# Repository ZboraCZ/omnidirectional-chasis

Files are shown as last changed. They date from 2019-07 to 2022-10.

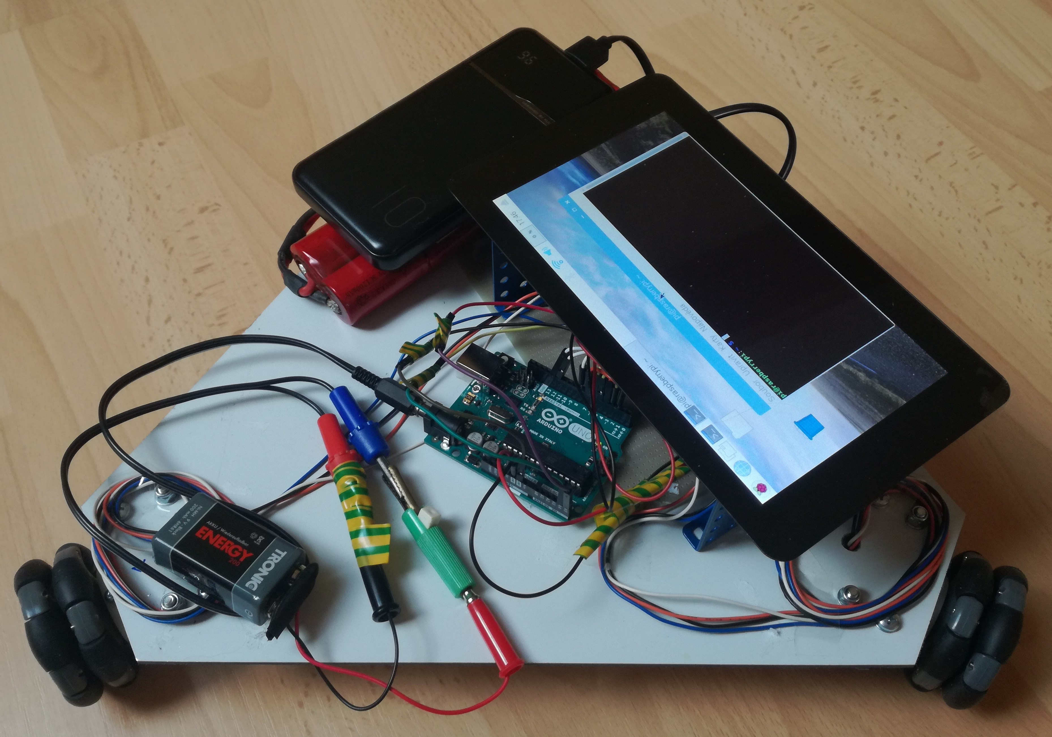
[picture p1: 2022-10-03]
Final_chasis_photo.jpg

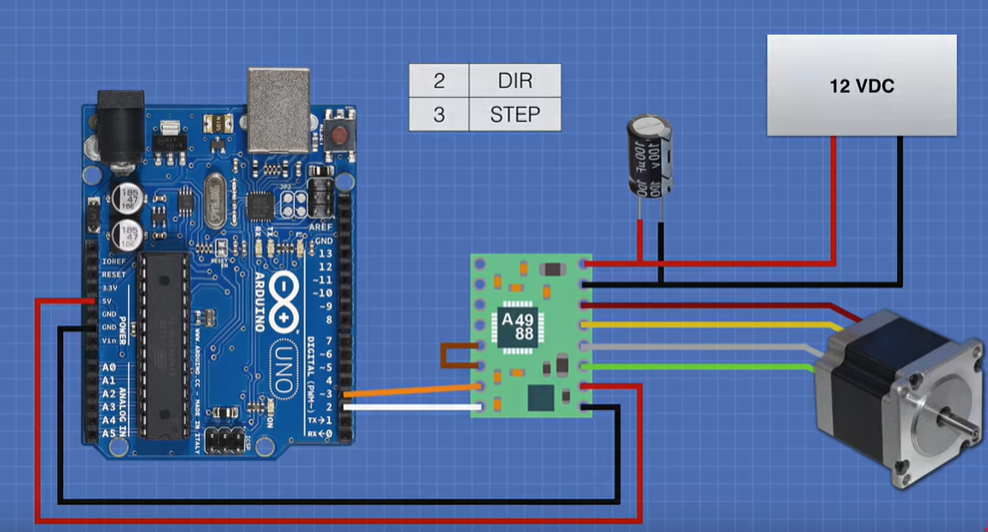
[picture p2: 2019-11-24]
Dokumentace/Obrázky/Zapojení_jednoho_motoru-UKÁZKA_YT.PNG

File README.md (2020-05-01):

# TODO list
* Max speed is 450. Needs to be replaced in codes from 200
* AND ITS TO 15 NOT 16 ON 4 BITS FFS WHAT AN IDIOT I AM
* AND THE CONSTANT FOR MODIFYING THE SPEED IS 30 YOU IDIOT
* disableOutputs enables to Arduino using motors. Its like negative
* Take photo of RPi and Arduino for Thesis.
* Build again just i2c comm Arduino-RPi
	* Make all new scripts bash executables: chmod a+x /path/to/file or chmod 777 /path/to/file
	* TOTEST: Response scripts from Arduino back to Raspberry Pi (new waiting method in RPi scripts)
	* Test all Instruction primitives
	* Try running the SQUARE combined instruction
* Try to build complete chasis with all motors on non-soldering array, try to USE ALL 3 100uF transistors from Arduino set
* Take photo of complete chasis build for Thesis.
* Take video of the chasis move.
	* Make a square move anticlockwise, rotate 360 left, then 360 right. Go the square back clockwise.
* Try build the chasis with all motors on soldering array, try to USE ALL 3 100uF transistors from Arduino set if worked
* LETS ROLL!

# Bachelor thesis: Design and control of omnidirectional chasis.

## Running Raspberry Pi Shell scripts manual
### go.sh [int degrees] [int speedLevel]
int degrees: ° from 0 to 360 defining the way chasis will go. 0° is right, 90° is front.
int speedLevel: Number from 1 to 16 defining how quickly will the motors rotate up to 200 steps per second.

### rotate.sh [int degrees] [int direction]
int degrees: ° from 0 to 360 defining how much will the chasis rotate.
int direction: Number 0 or 1. 0 is rotation left(anticlockwise), 1 is rotation right(clockwise)

### brake.sh
Doesn't take arguments. Holds the motors still.

### stop.sh
Doesn't take arguments. Disables powering of the motors.

### setSpeed.sh [int speedLevel]
int speedLevel: Number from 1 to 16 defining how quickly will the motors rotate up to 200 steps per second.
Just sets speed of motors. Doesn't move anything.

## Checking I2C connection addresses table on Raspberry Pi:
sudo i2cdetect -y 1

# Maybe for future controlling with PS4 Dualshock Controller device
Scripts in the folder "ZZZ_unused_Controlling_motors_PS4_controller"
Workflow to start control of the Raspberry Pi:
1. sudo ds4drv, then start controller //Dualshock 4 controller will connect
2. start Main.py to start controlling

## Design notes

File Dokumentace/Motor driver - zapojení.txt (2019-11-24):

Zapojení krokového motoru správným směrem pro kladná čísla - Otáčení na podvozku proti směru hodinových ručiček:
B2 oražová
A2 černá
A1 modrá
B1 bílá

MS1, MS2,MS3: Připojují se na 5V, pokud chceme měnit full step, 1/8 step nebo 1/16 step podle tabulky

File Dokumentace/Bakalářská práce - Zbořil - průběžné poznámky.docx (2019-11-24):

# Bakalářská práce – průběžné poznámky

# Původní návrh Matematiky počítání rychlostí motorů na Raspberry Pi v krocích

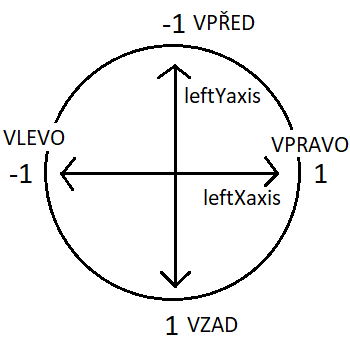
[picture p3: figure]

Plán ovládání podvozku byl takový, že bude ovládán analogovým ovladačem určeným pro herní konzole a jiné platformy. Od tohoto návrhu se ustoupilo hlavně z toho důvodu, že závislost na specifickém ovládacím zařízení je nežádoucí a nepraktická.

Kroky jsou určeny především pro levou páčku určující pohyb podvozku.

Předpoklad je ten, že uživatel pohnul jednou, nebo druhou páčkou. V opačném případě se nic neděje.

Hodnoty do daných směrů páček ovladače jsou popsány na obrázku.

# 1.krok

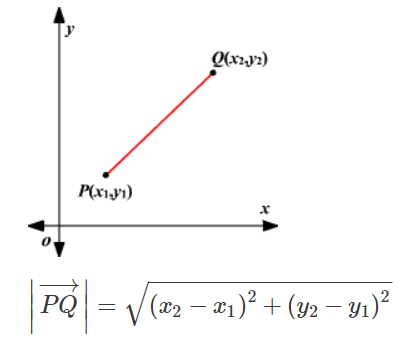
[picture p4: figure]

## Výpočet velikosti vektoru (jak daleko je páčka od jejího středu)

magnitude = math.sqrt( math.pow(leftXaxis, 2) + math.pow(leftYaxis, 2) )

# 1,5.krok-Důležitý mezikrok

## Ujištění se nepřekročení maximální hodnoty velikosti vektoru magnitude

Pokud se povede vypočítat velikost vektoru (dále jen magnitude) větší než 1, přiřadíme mu 1… Nesmíme překračovat hranice maximálních hodnot – otáčky motorů by mohly překročit hranici.

if magnitude > 1: magnitude = 1

# 2.krok

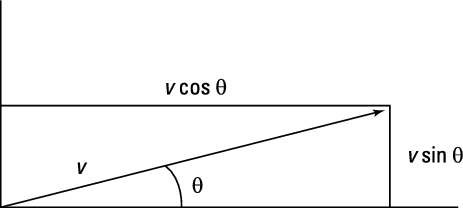
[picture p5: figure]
VÃ½sledek obrÃ¡zku pro direction of vector

## Určení směru vektoru páčky (direction of vector)

Směr vektoru je velikost úhlu od vodorovné osy X – nad osou je úhel kladný, pod osou záporný. Vzorec je dělení dvěma čísly, přičemž ani u jednoho se nepřipouští nulová hodnota, protože by rozbila celý výpočet. Minimální hodnotu blízko nule kterémukoliv číslu musíme oželit, i když to bude velice malá nepřesnost.
(Výsledek směru vektoru se v matematice označuje písmenkem THETA.)

if leftXaxis == 0: leftXaxis = 0.0000001
if leftYaxis == 0: leftYaxis = 0.0000001

direction = math.atan( leftYaxis/leftXaxis )

# 2,5.krok – Důležitý mezikrok

## Přepočet směru vektoru od 0° a nebo 180°(PI)

Zde přepočet vždy vychází správně pouze do 90° a v mé matematice vždy vycházela čísla pouze v úhlech vpravo od svislé osy Y. Musím zjistit, zda se posouvám vlevo nebo vpravo, a podle toho určit směr vektoru od 0° nebo 180°.

if leftXaxis < 0: direction = math.pi – direction

elif leftXaxis > 0: direction = 0 – direction

# 3.krok

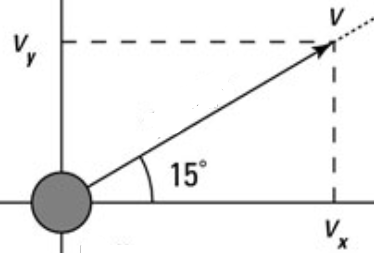
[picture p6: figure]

## Určení vektorových komponent Vx a Vy.

Využívá se zde směru páčky, který jsme vypočítali. Tyto vektorové komponenty poté ve finálním kroku slouží jako konstanty pro jasné určení jak rychlosti otáček jednotlivých motorů tak orientace jejich otáčení (vpřed nebo vzad).

vectorX = math.cos(direction) * magnitude
vectorY = math.sin(direction) * magnitude

# 4.krok

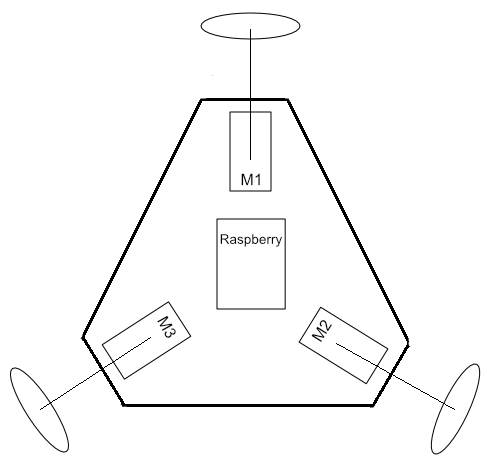
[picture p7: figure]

## Určení rychlostí jednotlivých motorů

Motor1 se pohybuje pouze na ose X, tedy počítání s komponentou Vy nemá význam.
Motor2 i Motor3 se pohybují v obou osách, vzorec je tedy o něco složitější.

motor1Speed = -1 * (vectorX)
motor2Speed = 0.5*vectorX + math.sqrt(3/2)*vectorY
motor3Speed = 0.5*vectorX - math.sqrt(3/2)*vectorY

# 5.krok

## Ujištění se maximálních hodnot pro motory a jejich vynásobení pro reálné přenesení na hodnoty pro jejich rotaci

Rychlost každého motoru se vynásobí 255ti, protože Arduino operuje s motory na hodnotách od 0 do 255. Poté se číslo zaokrouhlí na celé, aby přenos po sběrnici na Arduino nebyl moc velký.

if abs(motor1Speed) <= 1:
motor1Speed = int(round(motor1Speed * 255, 0))
else:
motor1Speed = int(motor1Speed) * 255

if abs(motor2Speed) <= 1:
motor2Speed = int(round(motor2Speed * 255, 0))
else:
motor2Speed = int(motor2Speed) * 255

if abs(motor3Speed) <= 1:
motor3Speed = int(round(motor3Speed * 255, 0))
else:
motor3Speed = int(motor3Speed) * 255

Nyní už probíhá pouze přenos hodnot pro motory na Arduino.

# Charakteristika I2C sběrnice

Sběrnice I2C používá společný hodinový signál (data se tedy přenáší synchronně), ovšem komunikace je poloduplexní – v jeden okamžik může existovat pouze jedno vysílající zařízení a libovolný počet zařízení (většinou však jen jedno), která data přijímají. Komunikace může probíhat oběma směry, sběrnice je tedy sériová. U sběrnice I2C také není použit výběr zařízení typu slave pomocí zvláštních signálů (CS), protože každému uzlu může být přiřazena jednoznačná adresa – kromě elektrických charakteristik je totiž ve specifikaci přesně stanoven i základní komunikační protokol, což je další – a to dosti podstatný – rozdíl oproti výše popsané sběrnici SPI. Obecně je možné říci, že I2C je sice poněkud složitější, ale zato flexibilnější sériovou externí sběrnicí, která se velmi často používá i pro komunikaci na delší vzdálenosti (řádově metry).

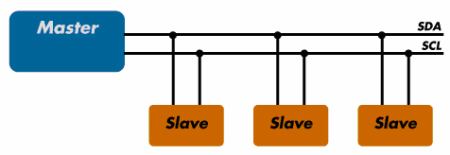
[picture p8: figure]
pc4402

Na obrázku je zobrazen princip propojení několika uzlů pomocí sběrnice I2C. Sběrnice je tvořena dvojicí signálových vodičů. První signálový vodič slouží pro obousměrný přenos dat (SDA – serial data), druhým vodičem pak zařízení typu master posílá všem ostatním zařízením hodinové signály (SCK – serial clock). V praxi je navíc nutné k této dvojici vodičů přidat i společnou signálovou zem (GND – ground). Ani to však ještě pro úspěšnou komunikaci nestačí, protože je navíc nutné oba signálové vodiče, tj. jak SDA, tak i SCK, připojit přes pull-up rezistory o odporu cca 1,5 kΩ na napájecí napětí. Důvod je jednoduchý – ve chvíli, kdy jsou všechny uzly nečinné (mohou být klidně i odpojeny od sběrnice), zvedají tyto dva rezistory napětí na obou signálových vodičích na úroveň logické jedničky, což je normou stanovený klidový stav. Sběrnice může v tomto stavu zůstat po libovolně dlouhou dobu – některé mikrořadiče dokonce mohou přejít do režimu „spánku“ (nízké spotřeby, snížení vyzařování) s tím, že při zahájení komunikace se automaticky aktivují.

Zdroj: https://www.root.cz/clanky/komunikace-po-seriove-sbernici-isup2supc/

# Komunikace Raspberry Pi a Arduina přes sběrnici I2C

Pro přesnou komunikaci a výměnu dat je nutné mít domluvený formát dat, který se bude mezi Raspberry Pi a Arduinem posílat. Pro všechny možné příkazy musí vyjít dostatek místa pro data, ale zároveň čím více je dat, tím pomalejší je přenos. Rozhodnutí tedy padlo na přenos několika bytů. Jednotlivé skupiny bitů v těchto bytech budou reprezentovat hodnotu, kterou požadujeme.

Byla provedena měření na přenos jednoho, dvou a tří bytů v určitém počtu opakování. Tyto byty obsahovaly naše požadovaná data. Posílání dat jedním bytem je málo, všechna data se nám na tak malý prostor nevejdou. Výsledek posílání dvěma byty se zvýšil časově od jednoho jen o 20 sekund, což ještě není špatné. Na 500 opakování je zpoždění 4 setiny vteřiny na každý přenos, což je čas, který je v reálném světě při komunikaci postradatelný. Výsledek posílání tří bytů po sběrnici ovšem nemile překvapil. Očekávání bylo, že čas se zvedne lineárně, tak jako mezi jedním a dvěma byty. Čas výsledku tohoto průběhu je více než dvojnásobný. Proběhly i pokusy snížit čekání na Raspberry Pi, aby se instrukce odesílaly rychleji, ale sběrnice v průběhu přenosu selhala a vyhodila chybovou hlášku, protože přenos nestíhala. Kdyby výsledek přenosu tří bytů byl lineární, nebo i trošku více, rozhodnutí by bylo těžké, možná i přiklánějící se přenosu tří bytů. Do tří bytů by se nám vlezly všechny potřebné hodnoty s opravdu vysokou přesností. Bylo by místo pro možná rozšíření v budoucnu. Graf s výsledky rozhodnul, že přenos dvou bytů je nejefektivnější varianta. Je rychlá a pro odesílaná data dostačující.

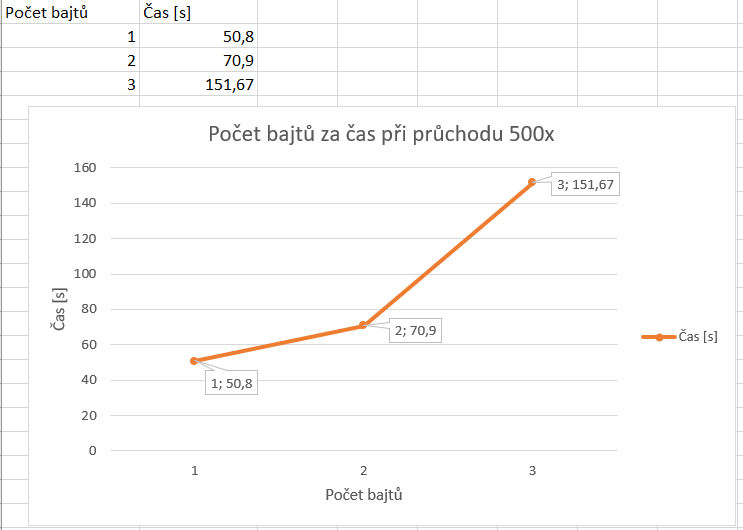
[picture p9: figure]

Ovšem s výběrem omezeného množství bytů přichází i řada problémů, které se musí vyřešit. Nevlezou se do bytů všechna čísla instrukce v původních hodnotách. Byte je číslo, které může nabývat pouze hodnot od 0 do 255. Obsahuje 8 bitů. Nemůžeme tedy přenášet informaci o úhlu, který může nabývat hodnoty až do 360 stupňů jen tak v jednom bytu. Prvním rozhodnutím bylo, že se 360 stupňů konstantou upraví na hodnotu nepřesahující maximum 255, abychom ve dvou bytech ušetřili místo. Z důvodu přebytku množství informací a nedostatku místa je nutné byty zkombinovat. Konec jednoho, a začátek druhého bytu bude obsahovat právě tuto upravenou hodnotu úhlu, který bude poté opět převeden na Arduinu stejným způsobem nazpět.

## Nastavení přenosu I2C

Raspberry bez dodatečných nastavení přes I2C komunikovat nemůže. Naší implementaci předchází řada nastavení na Raspberry, než jej můžeme začít používat. Musí se i2c smazat z blacklistu konfigurací, do /etc/modules se musí vepsat modul i2c-dev, nainstalovat balíček i2c-tools, přidat přístup k I2C sběrnici systémovému uživateli pi. Poslední věc pro možnost používání i2c rozhraní je nyní už pouze zkontrolovat, zda je jako interface (rozhraní) k používání povoleno. Po zadání příkazu raspi-config v terminálu se dostaneme do nejrůznějších nastavení Raspberry Pi. Naše hledaná záložka je Interfaces. Zde je právě možnost I2C Interface, na který klikneme, a Raspberry se nás zeptá, zda chceme tento interface povolit. Po těchto krocích Raspberry zrestartujeme. Poté už příkazem můžeme zobrazit tabulku s adresami, na kterých jsou připojená I2C zařízení. Nainstaluje se nyní knihovna pro jazyk Python (python-smbus) pomocí linuxového instalátoru balíčků apt-get install, která nám umožní ke sběrnici v kódu přistupovat.

Na Raspberry i Arduinu se musí nastavit stejná I2C adresa, přes kterou spolu budou komunikovat. Na Raspberry se nastaví pouze adresa 0x04, na Arduinu musíme definovat, že je Slave, neboli podřízený, a k němu nastavíme stejnou adresu 0x04. Definováním Arduina jako podřízeného řešíme také odlišnosti v hodnotě napájení mezi Raspberry a Arduinem. Raspberry totiž napájí na 3,3V, zatímco Arduino napájí na 5 V, což by mohlo směrem z Arduina na Raspberry způsobovat problémy. Jelikož jsme ale tuto cestu „utlumili“, tak jednosměrných 3,3 V z Raspberry směrem na 5 V Arduino nezpůsobuje žádné problémy. Na Raspberry se oba byty ve správném formátu uloží do pole. Do metody knihovny smbus pro I2C přenos se vkládají tři parametry. I2C adresa Arduina, offset neboli posunutí dat od začátku přenosu a samotná data (v tomto případě naše byty).

## Struktura přenášených bytů

Přenášíme tedy dva byty. Tyto dva byty jsou po vytvoření jejich struktury uloženy do pole a poslány na Arduino. Tyto dva byty mají následující strukturu jednotlivých bitů:

První byte:
Bity 1-3: Kód primitiva prováděné instrukce. Podle tohoto kódu se Arduino rozhoduje, jaký typ pohybu se provádí. Např. „Jet“, „Zatočit“, „Zabrzdit“, „Vypnout motory“, „Nastavit rychlost“.
Bity 4-8: První část parametru úhlu prováděné instrukce. Úhel je příliš velký. Je konstantou upraven na hodnotu nepřesahující 255, která se poté na Arduinu stejnou konstantou vrátí nazpět, abychom se opět pohybovali v celých 360 stupních.

Druhý byte:
Bity 1-3: Druhá část parametru úhlu prováděné instrukce. Úhel je příliš velký. Je konstantou upraven na hodnotu nepřesahující 255, která se poté na Arduinu stejnou konstantou vrátí nazpět, abychom se opět pohybovali v celých 360 stupních.
Bity 4-7: Hodnota vzdálenosti. Jednotka této hodnoty jsou centimetry. Může označovat, jak daleko má podvozek cestovat, popřípadě poloměr zatáčení atd…
Bit 8: Tzv. „Bezpečnostní bit“. Pokud je po provedení přenosu 1, data nebyla během přenosu poškozena. Pokud bude 0, data mohla být modulována nebo poškozena a příkaz se neprovede.

# Původní návrh získání všech hodnot z bytů na Arduinu

Na Arduinu byl deklarován řetězec, který k sobě jednotlivé vytažené bity přijaté instrukce přidával na konec. Aby k sobě řetězec mohl bity přidat, musely se bity převést z čísla na řetězec. Zde se návrh ukončil, než se vůbec došlo na výpočty a následné kontroly motorů. Práce s řetězcem zabírá velké množství místa i času. Když provádíme operace pouze nad číselnými datovými typy, v tomto případě typem byte, pracujeme obyčejně s jedním bytem, tedy hodnotami od 0 do 255. Když pracujeme s řetězcem, každý jeho znak zabírá 1 byte. Abychom tedy mohli využívat náš výsledný řetězec, který je v tomto případě dlouhý 16 znaků, musíme do něj všech 16 bytů vložit. Hodnoty z tohoto řetězce se vybíraly podle indexu začátku určité hodnoty, a indexu konce určité hodnoty. Například pro získání délky v centimetrech, kolik má náš podvozek ujet, musíme z řetězce vybrat hodnoty na pozicích 12-15. Tato operace je zdlouhavá a nežádoucí. Přešlo se tedy na bitové operace, které se používají u číselných datových typů.

# Použitý návrh získání hodnot z bytů na Arduinu

Binární číslo je reprezentováno posloupností binárních hodnot (jedniček a nul) a takto reprezentovaná čísla se používají v digitální technice.

Bitová operace (anglicky bitwise operation) je operace, která aplikuje určitou logickou operaci nikoliv na jednotlivé bity, ale na celé vektory bitů. Většina procesorů má strojové instrukce, které provádějí bitové operace. Tyto operace typicky nejsou pomalejší než provádění sčítání a odečítání.
Dalšími bitovými operacemi, které jsou dostupné jako strojové instrukce, jsou operace bitových posuvů a rotací. Posuv o jeden bit doleva lze interpretovat jako znásobení operandu číslem dvě, posuv o jeden bit doprava jako vydělení dvěma. Posuvy o více bitů pak jako násobení nebo dělení příslušnou mocninou čísla dvě. Posuvy o jeden bit jsou mnohem rychlejší než operace násobení a dělení. Posuvy o větší počet bitů se na některých procesorech provádějí opakovaným posuvem o jeden bit. Co se ovšem týče výpočtové náročnosti, naše číselné posuvy jsou mnohem rychlejší než transformace přes dlouhé řetězce.

# Bitové operace použité na Arduinu

V každém bytu je potřeba zjistit pouze určité skupiny bitů. V tomto případě třeba první tři, nebo prostřední 4 v druhém bytu. Nejrychlejší, a přitom stále jednoduchá operace pro zjištění těchto pár hodnot je operace bitového posuvu.

## Bitový posuv (bitshift)

Při provádění bitového posuvu se vezme celé číslo jako operand a aplikuje se na něj operátor „<<” (posuv vlevo) nebo “>>” (posuv vpravo), a za něj operand, o kolik míst se všechny bity posunou. Existují však různé druhy posuvu podle toho, jakými hodnotami vyplňuje krajní pozice.
Aritmetický posuv používá operátory „<<“ a „>>“. Respektuje kódování čísla, které je posouváno, a proto má i aritmetický význam - posuv o jednu pozici vlevo odpovídá násobení dvěma a posuv vpravo dělení. Opakovaným aritmetickým posuvem lze tedy velmi efektivně násobit a dělit mocninami čísla 2. V případě doplňkového kódu a záporného čísla (tzn. nejvýznamnější bit je 1) jsou směrem od nejvýznamnějšího nasouvány hodnoty 1, jinak 0. Tento typ posuvu je použit v naší implementaci, ovšem vždy se při posuvu generují na kraji nuly, protože nepracujeme se zápornými čísly.
Logický posuv používá operátory „<<<“ a „>>>“. Nemá žádný aritmetický význam, z obou krajních pozic generuje vždy nuly.
Příklad: Je potřeba zjistit první 3 bity prvního bytu pro zjištění našeho kódu primitive prováděné instrukce. Byte vypadá následovně: “11100101”. Arduino tento byte reprezentuje jako číslo. Tento byte je hodnota 229, ale není potřebná. Pro zjištění prvních tří bitů se provede operace „229 >> 5“. Celé číslo posunulo všechny své bity o 5 míst doprava. Nyní byte vypadá takto: “00000111”. Nyní jsme získali hodnotu, našeho primitva, podle kterého se budeme rozhodovat, jaký pohyb se bude provádět.

## Bitový součet

Bitový součet využívá operátor „|“. Také využívá dva operandy, ale tentokrát jsou jimi obyčejně naše dvě vybraná porovnávaná čísla. Bere dva bitové vzory o stejné délce a vytváří nový bitový vzor, jehož hodnota závisí na hodnotě vstupních bitových vzorů. Porovnává postupně jeden po druhém příslušné bity (první bit prvního vzoru s prvním bitem druhého vzoru, druhý bit prvního vzoru s druhým bitem druhého vzoru atd.) a provádí s každým párem logickou operaci OR (součet).
Příklad: Potřebuji spojit 5 bitů prvního bytu s prvními třemi bity druhého bytu, a získat tak úhel směru jízdy. Vezmeme si první byte z minulého příkladu: “11100101”. Bitový posuv o tři doprava nám vrátí byte, který bude mít na prvních pěti bitech naši první část bitů, poslední tři budou vždy nuly. Tedy „00101000“ (40). Druhý byte bude: “00101101” (45). Bitový posuv o pět doprava nám vrátí byte, který bude mít na posledních třech bitech naši druhou část bitů, prvních pět bitů budou vždy nuly. Tedy „00000001“ (1). Nyní proběhne součet prvního a druhého upraveného bytu a dostaneme náš správný hledaný úhel od 0 do 255. Proběhne tedy operace „40 | 1“, neboli (40+1). Je to jako obyčejný součet pod sebou 00101000 + 00000001. Tento součet upravené hodnoty musíme definovanou konstantou v programu vrátit zpět do maxima 360 stupňů.

Zdroj pro bitové operace: http://voho.eu/wiki/bit/

# Použitý návrh Matematiky pro motory na Arduinu v krocích

O tom, jakým způsobem se podvozek bude chovat, závisí na typu instrukce, kterou po něm budeme požadovat, tedy jaký typ instrukce od Raspberry Pi po I2C sběrnici Arduino přijme. Pro různé typy instrukcí se tedy vykonává jiná posloupnost výpočtů, podle kterých se poté motory, jakožto celý podvozek zachovají.

## Přímá jízda

Po přijmutí dat k tomuto typu instrukce víme před začátkem všech výpočtů dvě věci, které Arduino obdrželo, a je potřeba je ve výpočtu využít. První informace je úhel, který po přepočtení má hodnotu 0-360 stupňů. Druhá informace je vzdálenost, kterou podvozek pojede.

1) Zjistíme velikosti vektoru pohybu na ose X a ose Y pro daný úhel jízdy. Konstanta WHEELS_MAGNITUDE je nastavena na 1. Je zde pro případnou rychlou a jednoduchou úpravu celkové rychlosti všech motorů.
double vectorX = cos(receivedAngle) * WHEELS_MAGNITUDE;
double vectorY = sin(receivedAngle) * WHEELS_MAGNITUDE;

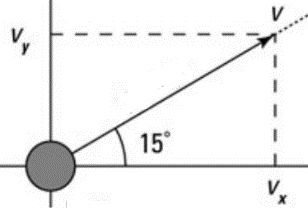
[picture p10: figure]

2) Zjistíme rychlosti otáček za sekundu pro jednotlivé motory.
Motor1 se pohybuje pouze na ose X, tedy počítání s komponentou Vy nemá význam. Motor2 i Motor3 se pohybují v obou osách, vzorec je tedy o něco složitější. Motory jsou od sebe s rozestupem 120 stupňů, proto v druhém vzorci můžeme vidět přičítání 120° v radiánech, a v třetím odečítání pro třetí motor. Když se na podvozek budeme dívat shora, kladné výsledné hodnoty otáčí koly proti směru hodinových ručiček, zatímco záporné po směru hodinových ručiček.
double motor1Speed = (-1 * vectorX) * MAX_RPS;
double motor2Speed = (0.5 * vectorX + sqrt(3)/2 * vectorY) * MAX_RPS;
double motor3Speed = (0.5 * vectorX - sqrt(3)/2 * vectorY) * MAX_RPS;

# Díly a součásti použité pro sestavení podvozku

# Zapojení krokového motoru k motor driveru A4988

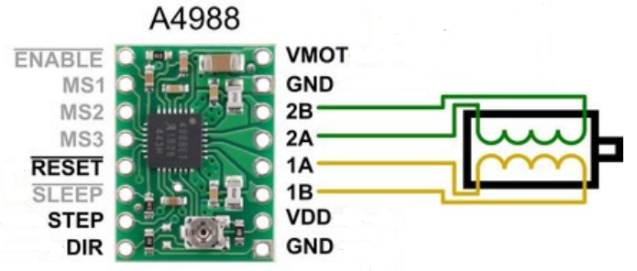
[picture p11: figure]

Krokové motory použité v této bakalářské práci jsou bipolární: Vedou z nich tedy čtyři dráty, z každého vinutí dva. Jeden pár drátů kontroluje polaritu jedné cívky elektromotoru, druhý pár kontroluje polaritu cívky druhé. Je tedy zásadní správně tyto dráty zapojit. Pokud bychom dráty zapojili špatně, například bychom pomíchali dráty mezi páry, motor by se v pozici mezi cívkami začal cukat a už by se dál neotočil. Způsobené by to bylo tím, že jsme zapojili jeden drát z každého páru na jednu cívku, což zapříčiní, že cívky jdou proti sobě.

1. Zapojení párů cívek k motor driveru

Zapojení jednotlivých fází těchto konkrétních krokových motorů je zobrazeno v dokumentech výrobce, firmy Microcon.

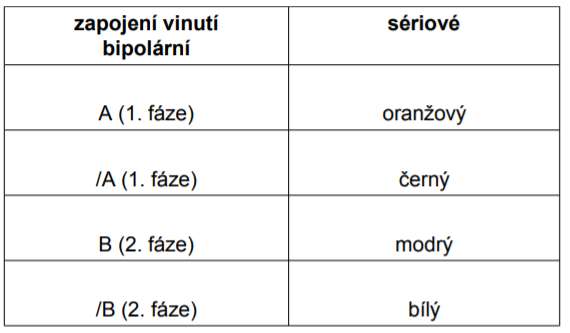
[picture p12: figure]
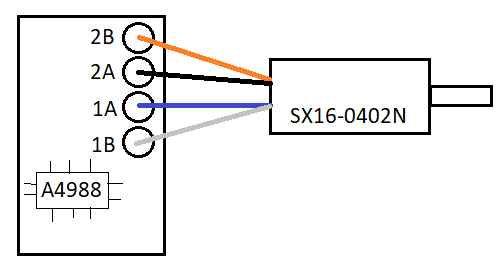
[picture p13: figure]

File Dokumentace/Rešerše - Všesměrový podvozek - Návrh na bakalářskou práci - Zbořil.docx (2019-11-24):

# Návrh bakalářské práce

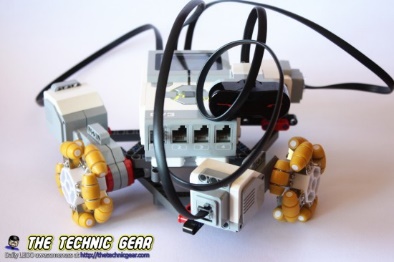
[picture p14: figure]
three-wheels-holonomic-robot

# Úvod

Při myšlenkách a procesích vytváření a sledování různých výtvorů jsem se nejvíce inspiroval stránkou http://thetechnicgear.com/2014/04/howto-build-3-wheels-holonomic-robot-using-lego/.
Na této stránce je popsán postup vytváření robota z lega a následně matematické postupy při jeho řízení.

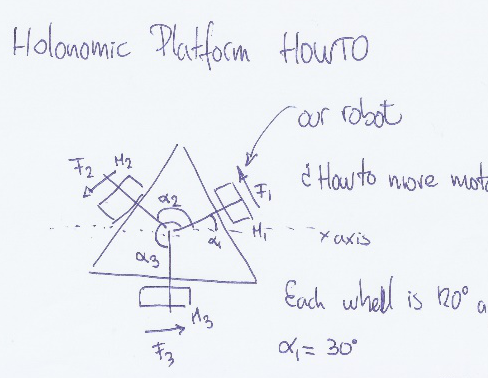
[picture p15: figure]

# Vzhled konstrukce podvozku

Podvozek bude tvaru rovnostranného trojúhelníku s rovně uřezanými vrcholy pro rovnoměrné umístění koleček. Uprostřed by bylo Raspberry nebo Arduino a můstky, drivery, baterie atd.

Druhou možností je dát kola do půlek stran trojúhelníku, tedy vrcholy zůstanou volné a neřízlé.

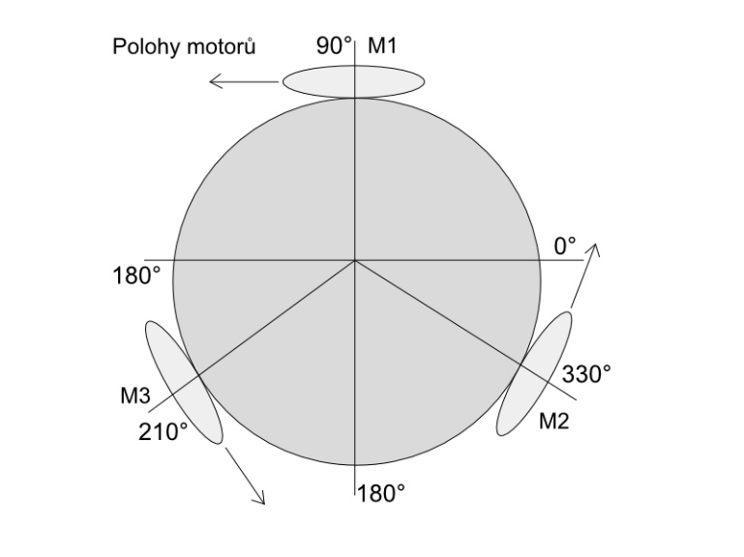
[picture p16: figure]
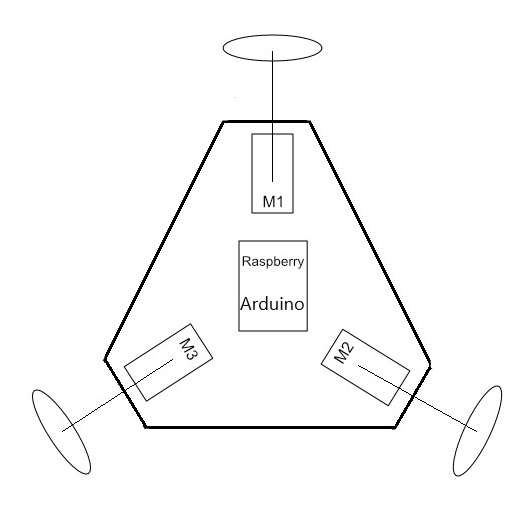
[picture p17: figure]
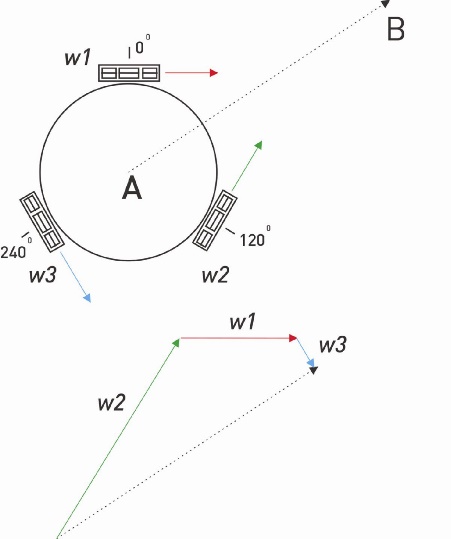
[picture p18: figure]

# Výběr součástek

## Motory

Motor by měl být stejnosměrný a nejlépe s dostatečným výkonem, ale nesmí se točit moc rychle pro jeho dostatečnou ovladatelnost. Nejlepší by mohl být 6 V, 12 V DC motor, který bude mít převodovku.

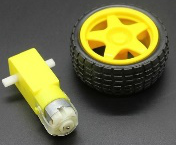
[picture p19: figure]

https://laskarduino.cz/robot-podvozek/170003-kolo-s-prevodovanym-motorem.html

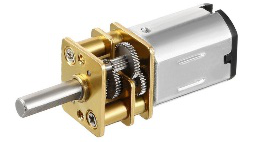
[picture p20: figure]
GA12-N20 motor s pÅ evodovkou

https://laskarduino.cz/motory-radice/230415-273-ga12-n20-motor-s-prevodovkou.html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

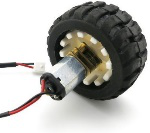
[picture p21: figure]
Kolo 43mm s pÅ evodovanÃ½m motorem N20

https://laskarduino.cz/robot-podvozek/230354-kolo-43mm-s-prevodovanym-motorem-n20.html

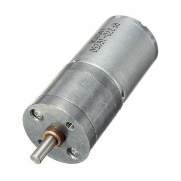
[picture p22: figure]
Foto - Motor 12V DC 60RPM s PÅ evodovkou SilnÃ½ ToÄ ivÃ½ moment 25mm

https://arduino-shop.cz/arduino/1466-motor-12v-dc-60rpm-s-prevodovkou-silny-tocivy-moment-25mm.html

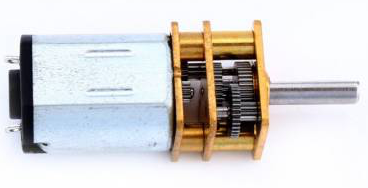
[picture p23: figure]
Foto - StejnosmÄ rnÃ½ motor s pÅ evodovkou DC 12V 300 RPM N20

https://arduino-shop.cz/arduino/3099-stejnosmerny-motor-s-prevodovkou-dc-6v-30-rpm-n20-2.html

## Možné použitelné motor drivery

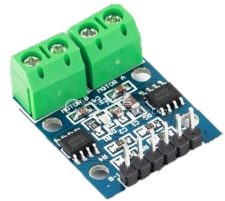
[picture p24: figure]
Foto - Arduino H-mÅ¯stek modul L9110S

Arduino driver L298N. 5–35 V. proud 2 A.
https://arduino-shop.cz/arduino/877-arduino-h-mustek-pro-krokovy-motor-l298n-dual-h-most-dc.html

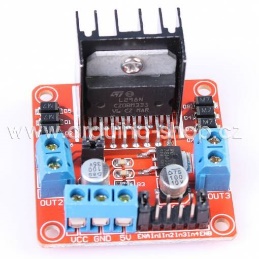
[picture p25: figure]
Foto - Arduino H mÅ¯stek pro krokovÃ½ motor L298N Dual H Most DC

Arduino motor driver l293d. 4.5-25 V, proud až 600 mA, ochrana proti přetížení.
https://arduino-shop.cz/arduino/916-arduino-motor-driver-l293d.html

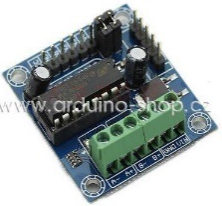
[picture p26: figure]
Foto - Arduino motor driver l293d

Můstek modul L9110S pro 2 DC motory. 2,5 – 12 V. Až 800 mA.
https://arduino-shop.cz/arduino/1233-arduino-h-mustek-modul-l9110s.html

# Raspberry Pi:


Protože se podvozek bude pohybovat po volném prostoru, musí být kontrolován nejlépe bezdrátově. Pohybovat se s robotem by bylo značně nepraktické. Řešení, které se mi podařilo najít, je ovládat jej přes Bluetooth ovladač Dualshock od Playstation 4. Do složky projektu si nainstaluji knihovnu driveru pro tento ovladač (ds4drv). Poté si nainstaluji také knihovnu Pygame.
Při spuštění pomocí příkazu $ sudo ds4drv Raspberry vyčká, dokud nezapneme ovladač pro synchronizaci a připojí jej. Tento konzolový ovladač mám nový doma, takže mohu používat jej. Video, které popisuje tuto instalaci a použití s ovladačem má odkaz tento:
https://www.youtube.com/watch?v=1EYtZC2iVzc

# Arduino:


U Arduina už jen tak knihovny na dálkové ovládání neseženeme. Bude potřeba nějaký modul. Bluetooth bude volbou. Nejjednodušší bude ovládat Arduino pomocí chytrého telefonu s Androidem. Bál jsem se podpory a možností komunikace mezi zařízeními, ale narazil jsem na zajímavé řešení na jednom videu, kde to vypadá jako hračka.
Jako BT přijímač je použita součástka Arduino bluetooth modul HC-05 (obrázek vpravo). Odkaz na součástku: https://arduino-shop.cz/arduino/1005-arduino-bluetooth-modul-hc-05.html.
K ovládání pak mohu použít aplikace dostupné na Obchodu Play Androidu. Našel jsem dvě, které používají klasické softwarové joysticky, a mají zdokumentované video použití.


Pokud bakalářská práce nepovoluje použití již takových předvytvořených programů, našel jsem platformu pro vývoj IoT mobilních aplikací, a musel bych si jednu vytvořit: https://evothings.com/

Schéma výsledného zapojení s BT přijímačem HC-05 je následující:


Schéma je samozřejmě navrženo pro autíčko s pohonem na dvě kola, byl by potřeba ještě jeden driver, který by ovládal třetí motor. Baterie by byly použity jiné podle motorů.

Odkaz videa se skládáním autíčka a použitím modulu: https://www.youtube.com/watch?v=Ap-SZHJF8wU

## Druhá možnost ovládání Arduina

Příkladem, jak postavit takové tříkolové ovládání drátově by mohla být stránka https://howtomechatronics.com/tutorials/arduino/arduino-dc-motor-control-tutorial-l298n-pwm-h-bridge/. Je použitý stejný driver L298N jako v předchozí bezdrátové variantě. Musel by se o jednu řídící desku rozšířit pro třetí kolo. Ovládáním může poté být joystick připojený drátově, ale tento způsob stejně řeší pouze směrový přesun, ne už otáčení podvozku na místě. To by potom byl potřeba ještě nějaký další směrový ovládací element, který by určoval otáčení po směru nebo v protisměru hodinových ručiček.


# Matematické výpočty

Zdroje pro výpočet holonomického pohybu podvozku jsem našel dva. Lépe vypadá konstrukce podvozku, kdy kola jsou ve vrcholech, a ne v půlkách jednotlivých stran. Podle tohoto rozhodnutí pro kola ve vrcholech vyberu až druhý návrh výpočtů.

## 1.Způsob řešení – kola v půlích stran


První stránka s výpočty, která je zároveň mojí inspirací a zmíněna úplně na začátku dokumentu, s videem i výpočty vypadá, že je správně, ačkoliv jsem se na to zatím jen díval a vůbec tomu nerozumím.
http://thetechnicgear.com/2014/04/howto-build-3-wheels-holonomic-robot-using-lego/

## 2.Způsob řešení – kola ve vrcholech


Druhá stránka s výpočty je postupem lehce názornější a vysvětluje výpočet jednoduše. Je uvedeno schématické vyjádření problému a následně zápis vypočtení (zhruba v půlce článku). Tento článek vypadá jako dobré řešení, ovšem výpočet rychlostí jednotlivých kol se nezdá být přesný, a musí být opraven na přesnější hodnoty.
https://makezine.com/projects/make-40/kiwi/

# Moje dotazy a nejasnosti

-Pro kontrolu: H-můstek jako součástka dokáže měnit pouze směr otáčení, motor driver i otáčky?
-Kompatibilita Raspberry s Arduino součástkami snad není problém?
-Podle informací poskytuje Raspberry Pi PWM (Pulse width modulation) pro regulaci otáček pouze na dvou pinech. Já potřebuji pro svoje 3 kolečka alespoň 3 piny. Arduino jich má mnohem víc, konkrétně Arduino Uno má těchto PWM pinů 6. Tím pádem bych Raspberry nemohl použít?

# Závěr

Raspberry Pi je navrženo pro mnohem vyšší datové toky, ale není navrženo pro složitou manipulaci s motory a mechanickými prvky. Je spíše určeno pro vyhodnocování dat z kamer, složitějších logických programových struktur a AI technologie.

Arduino na druhou stranu zase skvěle pracuje s hardwarovými prostředky a pro mechanické použití v zápřahu je dělané více než Raspberry. Samozřejmě s mínusem dalšího řešení jeho ovládání přes přídavné moduly jako jsou Bluetooth nebo WiFi.

Motory jsou v této práci věc, kterým moc nerozumím. Pořádně nevím, jak se pro jaký rozhodnout. Všechny motory, které jsem prohlížel mají otáčky v jednotkách tisíců nebo desetitisíců, což je pro podvozek, co se nemusí pohybovat závratnou rychlostí, podle mě, zhola zbytečné. Je jasné, že se motor musí zpřevodovat převodovkou, ale s těmi už se obyčejně kupují. Jestli pro takový podvozek stačí motor, co má 60 otáček za minutu už nevím. První, které jsou vybrané v sekci motorů, jsou jen šestivoltové a podporují podle specifikací webu od 50 ti nebo 60 ti otáček a více. Určitě bych nechal toto rozhodnutí ohledně motorů na někom jiném než na sobě.

Samozřejmě se musejí vzít v potaz prostředky a možnosti školy. Toto jsou jen návrhy a prospekty, které jsem si hledal a shledal za možnosti, které by se daly použít, a taky pro ukázku, jak na to pohlížím a jestli správně.

Návrh bakalářské práce Návrh a řízení všesměrového podvozku Jiří Zbořil B-II-ARI

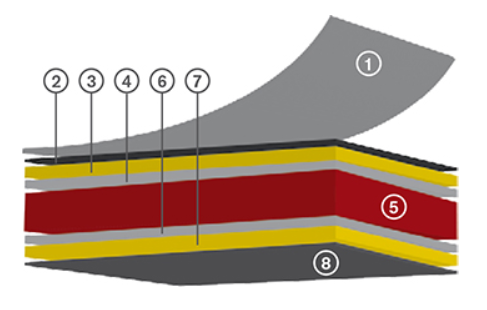
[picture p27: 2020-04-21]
Dokumentace/Obrázky/Alubond-rez.PNG

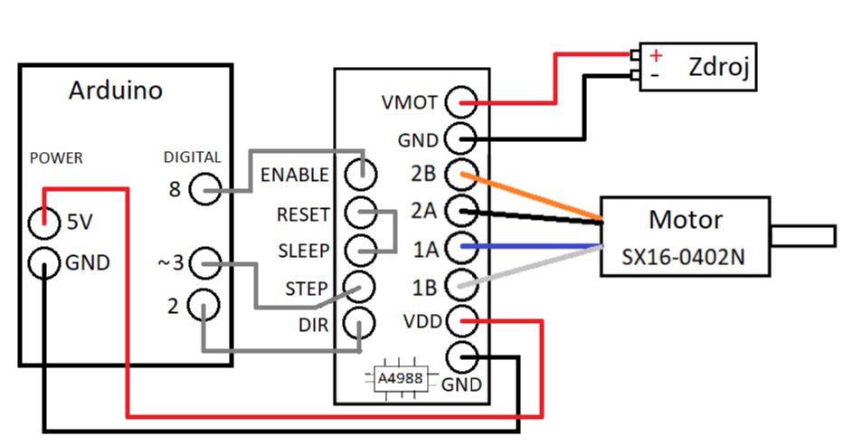
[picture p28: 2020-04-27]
Dokumentace/Obrázky/Zapojení_A4988.png

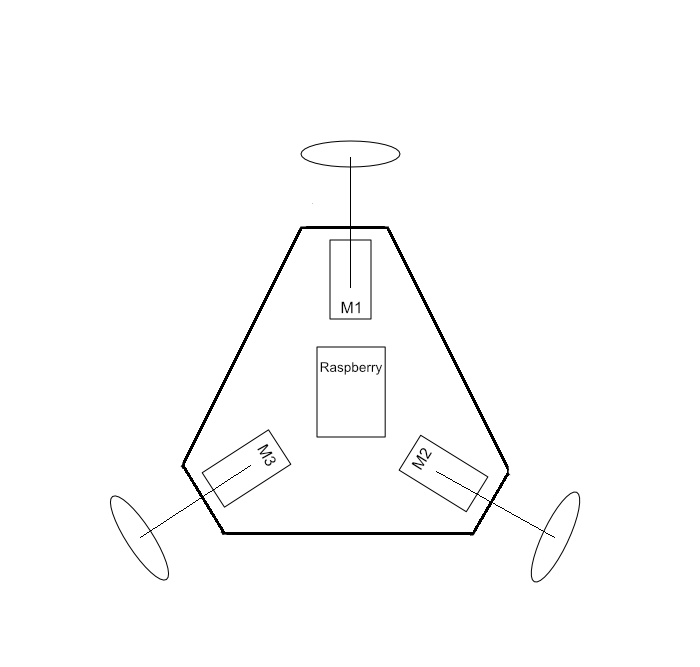
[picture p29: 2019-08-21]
Dokumentace/Obrázky/Kresba konstrukce podvozku.jpg

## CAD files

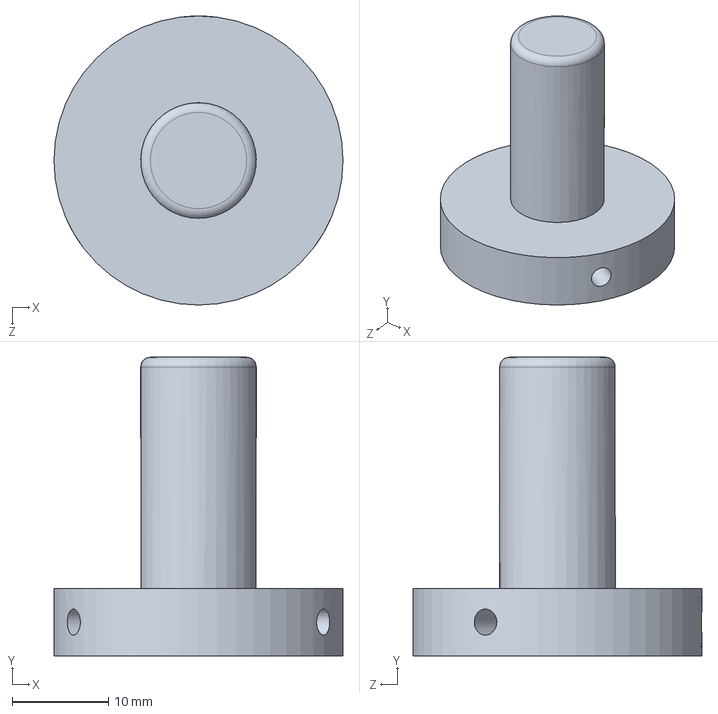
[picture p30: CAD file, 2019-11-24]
Konstrukce_podvozku_díly/Tisknuti-3D_dily/Spojnik-Prechod-Kolecko-Motor.SLDPRT
30.0 x 31.0 x 30.0 mm

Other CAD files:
Konstrukce_podvozku_díly/Tisknuti-3D_dily/Spojnik-Prechod-Kolecko-Motor.STL

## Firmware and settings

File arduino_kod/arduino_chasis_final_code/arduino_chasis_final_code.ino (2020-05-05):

#include <Wire.h>
#include <AccelStepper.h>

#define SLAVE_ADDRESS 0x04

//Const for converting degrees to radians for math calculations of motor movements
const double CONV_DEG_TO_RAD = 0.01745329251;
//Steps multiplier for max. speed level 15 from RPi into max of 240 SPS
const int STEP_MULTIPLIER = 16;

//MOTORS AND WHEELS DECLARATIONS 
// Diameter of wheels in cm
const double WHEELS_DIAMETER = 5.5;
//Wheels circumference in cm (Obvod kola)
const double WHEELS_CIRCUMFERENCE = WHEELS_DIAMETER * PI; //=17.27875
const double CHASIS_CIRCUMFERENCE = round(2 * PI * 18); // =113.097335529  18 is chasis radius ending at the center of wheel
const double CM_ON_ONE_DEGREE_CHASIS_ROTATION = CHASIS_CIRCUMFERENCE/360;  // = 0.35 [cm]
const double MOTOR_STEPS_PER_ONE_CHASIS_DEGREE_ROTATION = CM_ON_ONE_DEGREE_CHASIS_ROTATION/(WHEELS_CIRCUMFERENCE/200); //=7,292194287...   WHEELS_CIRCUMFERENCE/360 is about 0.047996527...
//Max steps per second for AccelSteper library
const int MAX_SPS = 240;

boolean instructionToDo = false;
byte instructionPrimitiveCode = 255;
double receivedAngle = 0;
//Unmodified received speedLevel. Is used for some identifications
byte speedLevel = 0;
//Modifier for all Motors speeds multiplications. 
//Goes to max 240, this is default, if "Go" doesnt go first to set it.
int speedModifier = 200;
byte secureBit = 1;

//##############################################################################
//####################### MOTOR DECLARATION SECTION ############################
//##############################################################################
// Define stepper motor connections and motor interface type. Motor interface type must be set to 1 when using a driver:
#define motorInterfaceType 1
const int M1_DIR_PIN = 2; const int M1_STEP_PIN = 3;
const int M2_DIR_PIN = 4; const int M2_STEP_PIN = 5;
const int M3_DIR_PIN = 7; const int M3_STEP_PIN = 6;

AccelStepper motor1 = AccelStepper(motorInterfaceType, M1_STEP_PIN, M1_DIR_PIN);
AccelStepper motor2 = AccelStepper(motorInterfaceType, M2_STEP_PIN, M2_DIR_PIN);
AccelStepper motor3 = AccelStepper(motorInterfaceType, M3_STEP_PIN, M3_DIR_PIN);

//####################### END OF MOTOR DECLARATION SECTION ############################
  
void setup() {
    
  //Setting enable pins to be able to turn of powering motors to not burn them down by staying still
  //Motors are enabled only when they are moving. Otherwise are disabled(powered off)
  motor1.setEnablePin(8);
  motor2.setEnablePin(12);
  motor3.setEnablePin(13); 
  disableMotorsPower();

  //Sets max steps per second to motors. If higher than 1000, Stepper gets inconsistent.
  motor1.setMaxSpeed(MAX_SPS); 
  motor2.setMaxSpeed(MAX_SPS); 
  motor3.setMaxSpeed(MAX_SPS); 

  ////////CONFIGURING I2C COMMUNICATION//////
  Serial.begin(9600); // start serial for output
  // initialize i2c as slave
  Wire.begin(SLAVE_ADDRESS);

  // define callbacks for i2c communication
  Wire.onReceive(receiveData);

}

    //######################################################
      //########## APPLICATION MAIN LOOP #############
    //######################################################

void loop() {
if(instructionToDo){
  instructionToDo = false;
if(secureBit == 1){
    if(instructionPrimitiveCode == 7){
        speedModifier = round(speedLevel * STEP_MULTIPLIER);
        receivedAngle = receivedAngle * CONV_DEG_TO_RAD;
        double vectorX = cos(receivedAngle);
        double vectorY = sin(receivedAngle);
   
        if (speedLevel == 0) speedLevel = 1;
        
        enableMotorsPower();
        
        //Calculate SPS for each motor <0,240>
        double motor1Speed = (-1 * vectorX) * speedModifier;
        double motor2Speed = (0.5 * vectorX + sqrt(3)/2 * vectorY) * speedModifier;
        double motor3Speed = (0.5 * vectorX - sqrt(3)/2 * vectorY) * speedModifier;

        //Set speed by RPS for each motor
        motor1.setSpeed(motor1Speed); motor2.setSpeed(motor2Speed); motor3.setSpeed(motor3Speed);
        
        // Run all motors for 3 seconds      
        int i=0;
        unsigned long startMillis = millis();
        while((millis() - startMillis) < 3000)
        {
        
          motor1.runSpeed();
          motor2.runSpeed(); 
          motor3.runSpeed();  
          delay(1);
        }
        disableMotorsPower(); 
        
    } //GO INSTRUCTION END

    else if(instructionPrimitiveCode == 5){

        enableMotorsPower();

        //SETTING CURRENT POSITION RESETS SPEED TO 0. HAS TO BE BEFORE SETTING SPEED ON MOTORS!!!        
        motor1.setCurrentPosition(0); motor2.setCurrentPosition(0); motor3.setCurrentPosition(0);

        double finishPosition;
        //speedLevel is here 0 or 1. 0 for rotation left(+ motors values), 1 rotation right(- motors values)
        //rotating left
        if (speedLevel == 0) { 
          finishPosition =  round(receivedAngle * MOTOR_STEPS_PER_ONE_CHASIS_DEGREE_ROTATION); 
          motor1.setSpeed(speedModifier); motor2.setSpeed(speedModifier); motor3.setSpeed(speedModifier);
        }
         //rotating right
        else if (speedLevel == 1){
          finishPosition = -1*round(receivedAngle * MOTOR_STEPS_PER_ONE_CHASIS_DEGREE_ROTATION); 
          motor1.setSpeed(-1*speedModifier); motor2.setSpeed(-1*speedModifier); motor3.setSpeed(-1*speedModifier);
        }
        // Running motors. Controlling just motor1 position, because they all run the same
        while(motor1.currentPosition() != finishPosition){
          motor1.runSpeed(); motor2.runSpeed(); motor3.runSpeed();
          delay(1);
        }
        
        disableMotorsPower(); 
        
    } //ROTATE INSTRUCTION END

    else if(instructionPrimitiveCode == 4){
        //Just enabling power to stepper motors and not moving them. 
        //Because they are powered up and holding their position TIGHT
        enableMotorsPower();
    }

    else if(instructionPrimitiveCode == 1){
      speedModifier = round(speedLevel * STEP_MULTIPLIER);
      motor1.setSpeed(speedModifier); motor2.setSpeed(speedModifier); motor3.setSpeed(speedModifier);  
    }

    else if(instructionPrimitiveCode == 0){
        disableMotorsPower();
    }

} //if(secureBit == 1) END
} //if instructionToDo END

//Serial.println("Loop end.");
} //void loop() END


//Actually the AccelStepper library has like inverted functions for enable/disable motors usage
//AccelStepper::motor1.enableOutputs() actually disables, disableOutputs() enables... funny huh?
//Function turns OFF the power to the motor coils to not burn them, saving power too
void disableMotorsPower(){
  motor1.enableOutputs(); 
  motor2.enableOutputs();
  motor3.enableOutputs();
}

//Function turns ON the power to the motor coils to not burn them, saving power too
void enableMotorsPower(){
  motor1.disableOutputs(); 
  motor2.disableOutputs();
  motor3.disableOutputs();
}



    //######################################################
      //########## RECEIVING DATA FROM RPI #############
    //######################################################
    
// Process received bytes from RPi to move
void receiveData(int byteCount) {
  //Const for converting 1 byte(max 255) back to 360 degrees sent from RPi
  const double CONV_DEGREES = 1.4117647058823529411764; //MUST MATCH CONST ON RPi for valid nums.
  // this is the acutal being read number from the I2C bus
  byte receivedNumber = 0;
  // We are getting 2 values.
  //1st byte is 3 bits of instruction primitive (go, turn, rotate, stop,...) and 5 bits of angle 
  //2nd byte is another 3 bits of angle, 4 bits of number in centimeters, last is Security bit
  int nthValue = 1;
  
  int offsetIndexesOfBytes = byteCount/2; // each offset is for 1 byte... using this int in FOR loop to jump over them as they are starting nums.
  
  byte m_instructionPrimitiveCode;
  byte m_firstHalfDegrees;
  byte m_secondHalfDegrees;
  byte m_receivedAngle;
  byte m_speedLevel;
  byte m_secureBit;
  /* Debugging
  for(int i =0; i<=byteCount; i++){ //hopping over the starting offset indexes
      receivedNumber = Wire.read();
      /*
      Serial.println(byteCount);
      Serial.println(receivedNumber);
      Serial.println("%%%%%%%%%%%");
      
    }
    */
  for(int i =0; i<offsetIndexesOfBytes; i++){ //hopping over the starting offset indexes
      receivedNumber = Wire.read();
    }
    
  nthValue = 1;
  while (Wire.available()) {
    receivedNumber = Wire.read();

    switch( nthValue ) {
      //First byte arrived (3 bits: instruction primitive code; 5 bits: first half of middle number)
      case 1: 
        m_instructionPrimitiveCode = receivedNumber >> 5;
        m_firstHalfDegrees = receivedNumber << 3;
        nthValue++;
        break; 

      //Second byte arrived (3 bits: second half of middle number; 4 bits: speedLevel measurement [cm], 1 bit: secure bit)
      case 2: 
        m_secondHalfDegrees = receivedNumber >> 5;
        m_speedLevel = receivedNumber << 3; m_speedLevel = m_speedLevel >> 4;
        m_secureBit = bitRead(receivedNumber, 0); //2nd parameter is nth position of bit from right
        nthValue = 1;
        break;
    }
  }

  //OR bit algebra operation: connect last 5 bits of first byte and first 3 bits of second byte to 1 byte
  m_receivedAngle = m_firstHalfDegrees | m_secondHalfDegrees;

  //FINAL VARIABLES ASSIGNMENTS
  instructionPrimitiveCode = m_instructionPrimitiveCode;
  receivedAngle = round(m_receivedAngle * CONV_DEGREES);
  speedLevel = m_speedLevel;
  secureBit = m_secureBit;
  
  instructionToDo = true;
  
} //End of setting received data

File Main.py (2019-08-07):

# README: First you need to connect gamepad ->  $ sudo ds4drv
# poznamka: Shortcut pro komentovani/odkomentovani bloku kodu -> Ctrl + #
import pygame
from DisplayController import DisplayController
from GamepadController import GamepadController

# Initialize pyGame library for PS4 controller to use it
pygame.init()

# Loop until the user clicks the close button.
applicationFinished = False

# Manage how fast the screen updates
clock = pygame.time.Clock()

# Instantiate class for printing to app window and control of the Gamepad
displayController = DisplayController()
gamepadController = GamepadController()


# -------- Main Application Loop -----------
while applicationFinished is False:
    # EVENT PROCESSING STEP
    for event in pygame.event.get():  # User did something
        if event.type == pygame.QUIT:  # If user clicked close
            applicationFinished = True  # Flag that we are done so we exit this loop

        # Possible joystick actions: JOYAXISMOTION JOYBALLMOTION JOYBUTTONDOWN JOYBUTTONUP JOYHATMOTION
        if event.type == pygame.JOYBUTTONDOWN:
            print("Joystick button pressed.")
        if event.type == pygame.JOYBUTTONUP:
            print("Joystick button released.")

    # First, clear the screen to white. Other drawing commands above this will be erased with this command.
    displayController.fillScreen('white')

    # set default position and line height of window
    displayController.reset()

    displayController.print("Number of joysticks: {}".format(gamepadController.joystick_count))
    displayController.indent()

    # For each joystick:
    for i in range(gamepadController.joystick_count):
        joystick = gamepadController.getJoystick(i)
        joystick.init()

        displayController.print("Joystick {}".format(i))
        displayController.indent()

        # Get the name from the OS for the controller/joystick
        joystickFactoryName = joystick.get_name()
        displayController.print("Joystick name: {}".format(joystickFactoryName))


        ##### CUSTOM EDIT TO GET AXES AND ITS AXIS #####

        # Blank line for block separation
        displayController.print("")

        ###LEFT JOYSTICK###

        # GO LEFT ; RIGHT -1.0 ; 1.0 #
        leftXaxis = round(joystick.get_axis(0), 3)
        if abs(leftXaxis) < 0.1: leftXaxis=0.0

        # GO FORWARD ; BACKWARD -1.0 ; 1.0 #
        leftYaxis = round(joystick.get_axis(1), 3)
        # Pocita se s malymi odchylkami, kdyz jsu packy v klidu, at nam nelita podvozek
        if abs(leftYaxis) < 0.1: leftYaxis=0.0

        ###RIGHT JOYSTICK###
        # ROTATE LEFT ; RIGHT -1.0 ; 1.0 #
        rightXaxis = round(joystick.get_axis(2), 3)
        # Pocita se s malymi odchylkami, kdyz jsou packy v klidu, at nam nelita podvozek
        if abs(rightXaxis) < 0.1: rightXaxis=0.0

        # Recalculate wrong values, on 1 or -1 and not 0 on the other direction
        # Wrong values are caused by some little hardware incompatibility
        if abs(leftXaxis) == 1 and leftYaxis != 0:
            leftXaxis = gamepadController.calculateLeftXaxisValueByPythagorasTheorem(leftXaxis, leftYaxis)

        elif abs(leftYaxis) == 1 and leftXaxis != 0:
            leftYaxis = gamepadController.calculateLeftYaxisValueByPythagorasTheorem(leftXaxis, leftYaxis)

        ###### Print joystick values to the screen ######
        # Print LEFT TO RIGHT DIRECTION VALUE
        #first round the values again - after pythagoras recalcs, numbers are wide
        leftXaxis = round(leftXaxis, 3)
        leftYaxis = round(leftYaxis, 3)
        displayController.print("GO LEFT ; RIGHT (-1.0 : 1.0): {}".format(leftXaxis))
        displayController.print("")

        # Print FORWARD TO BACKWARD DIRECTION VALUE
        displayController.print("GO FORWARD ; BACKWARD (-1.0 : 1.0): {}".format(leftYaxis))
        displayController.print("")

        # Print LEFT TO RIGHT ROTATION VALUE
        displayController.print("ROTATE LEFT ; RIGHT (-1.0 : 1.0): {}".format(rightXaxis))
        displayController.print("")

        # TODO - calculate values and send them to arduino
        gamepadController.calculateVelocitiesOfWheels(leftXaxis, leftYaxis, rightXaxis)

        ##### END OF MY CUSTOM EDIT FOR AXES #####

    # ALL CODE TO DRAW SHOULD GO ABOVE THIS COMMENT

    # Go ahead and update the whole screen with what we've drawn.
    pygame.display.flip()

    # Limit to 2.6 frames per second | 2.6 IS THE HIGHEST STABLE number
    # 2.6-cca sleep 384ms mezi loopy, 2.5-sleep 400ms mezi loopy
    clock.tick(2.6)

# Close the window and quit.
# If this line forgotten, the program will 'hang' on exit if running from IDLE.
pygame.quit()

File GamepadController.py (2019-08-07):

import RPi.GPIO as GPIO
import pygame
import math
import time
from smbus2 import SMBusWrapper


class GamepadController:
    # Constant with arduino Slave address to send computed values of motors to
    ARDUINO_ADDRESS = 0x04
    
    # Constructor for whole class controlling all the gamepads
    def __init__(self):
        # Initialize the functionalities with joysticks
        pygame.joystick.init()

        # Attribute Count of joysticks
        self.joystick_count = pygame.joystick.get_count()

    # Get specific Joystick instance of the joystick list
    def getJoystick(self, idNumber):
        return pygame.joystick.Joystick(idNumber)

    # Correct X movement value by recalculating its wrong value caused by little incompatibility
    def calculateLeftXaxisValueByPythagorasTheorem(self, leftXaxis, leftYaxis):
        return math.sqrt(1-math.pow(leftYaxis, 2)) * leftXaxis

    # Correct Y movement value by recalculating its wrong value caused by little incompatibility
    def calculateLeftYaxisValueByPythagorasTheorem(self, leftXaxis, leftYaxis):
        return math.sqrt(1-math.pow(leftXaxis, 2)) * leftYaxis

    # Calculate speeds (velocities of all wheels)
    # params leftXaxis: GO LEFT ; RIGHT (-1.0 : 1.0)
    # leftYaxis: GO FORWARD ; BACKWARD (-1.0 : 1.0)
    # rightXaxis: ROTATE LEFT ; RIGHT -1.0 ; 1.0
    def calculateVelocitiesOfWheels(self, leftXaxis, leftYaxis, rightXaxis):
        if not (abs(leftXaxis) == 0 and abs(leftYaxis) == 0 and abs(rightXaxis) == 0):

            # Jak rychle chceme jet => Jak moc je vyklonena packa
            magnitude = math.sqrt( math.pow(leftXaxis, 2) + math.pow(leftYaxis, 2) )
            if magnitude > 1: magnitude = 1

            # Predejiti uplnym nulam u smeru vektoru jizdy-Tyto vysledne nuly by mely nezadouci ucinky, popripade Vyjimky
            if leftXaxis == 0: leftXaxis = 0.0000001
            if leftYaxis == 0: leftYaxis = 0.0000001

            # Smer vektoru jizdy => uhel packy... neboli uhel od vodorovne osy x v rad => THETA
            direction = math.atan( leftYaxis/leftXaxis )

            # Kdyz se jede doleva, uhel vychyleni od osy X se odecita od PI(180°)
            if leftXaxis < 0: direction = math.pi - direction
            # Kdyz se jede doprava, uhel vychyleni od osy X se odecita od nuly(0°)
            # POZNAMKA: Kdyz leftXaxis bylo na zacatku 0, nastavilo se vyse na 0.0000001, tedy spadne do teto vetve
            elif leftXaxis > 0 and leftYaxis <= 0: direction = 0 - direction
            
            elif leftXaxis > 0 and leftYaxis > 0: direction = 2*math.pi - direction
            
            #Vypocet vektoru X a vektoru Y
            vectorX = math.cos(direction) * magnitude
            vectorY = math.sin(direction) * magnitude
            
            print('magnitude: ' + str(magnitude))
            print('direction: ' + str(direction))
            print('vectorX: ' + str(vectorX) + '; vectorY: ' + str(vectorY))

            # nastaveni finalniho otaceni na motorky
            # Arduino zadava motorkum rozpeti od 0 do 255, proto nasobime desetinne cislo 255kou
            # zaokrouhluje se na cela cisla, kvuli I2C prenosu
            motor1Speed = -1 * (vectorX)
            motor2Speed = 0.5*vectorX + math.sqrt(3/2)*vectorY
            motor3Speed = 0.5*vectorX - math.sqrt(3/2)*vectorY

            # Ujisteni ze zadna hodnota nepresahuje plnou rychlost (1 nebo -1) a pote vynasobeni 255kou
            # Je predpokladano, ze v else nad 2ku se zadnej speed nedostane, proto int() -> odebere desetinne casti
            if abs(motor1Speed) <= 1:
                motor1Speed = int(round(motor1Speed * 255, 0))
            else:
                motor1Speed = int(motor1Speed) * 255

            if abs(motor2Speed) <= 1:
                motor2Speed = int(round(motor2Speed * 255, 0))
            else:
                motor2Speed = int(motor2Speed) * 255

            if abs(motor3Speed) <= 1:
                motor3Speed = int(round(motor3Speed * 255, 0))
            else:
                motor3Speed = int(motor3Speed) * 255
                
            if abs(rightXaxis) <= 1:
                rightXaxis = int(round(rightXaxis * 255, 0))
            else:
                rightXaxis = int(rightXaxis) * 255

            print('-----Motory pred upravou pro odeslani-----')
            print(str(motor1Speed) + ' ' + str(motor2Speed) + ' ' + str(motor3Speed) + ' | ' + str(rightXaxis))

            # Prepsani hodnot motoru pouze na kladna cisla a za ne pridani indexu 
            # Kladna hodnota mtorou -> 1 | Zaporna hodnota motoru -> 0
            if motor1Speed < 0:
                indexMotor1Speed = 0
                motor1Speed = abs(motor1Speed)
            else:
                indexMotor1Speed = 1

            if motor2Speed < 0:
                indexMotor2Speed = 0
                motor2Speed = abs(motor2Speed)
            else:
                indexMotor2Speed = 1

            if motor3Speed < 0:
                indexMotor3Speed = 0
                motor3Speed = abs(motor3Speed)
            else:
                indexMotor3Speed = 1
                
            if rightXaxis < 0:
                indexRightXaxis = 0
                rightXaxis = abs(rightXaxis)
            else:
                indexRightXaxis = 1

            print('-----Motory po uprave pro odeslani-----')
            print(str(motor1Speed) + ' ' + str(indexMotor1Speed) + ' '+ str(motor2Speed) + ' ' + str(indexMotor2Speed) + ' ' + str(motor3Speed) + ' ' + str(indexMotor3Speed) + ' | ' + str(rightXaxis) + ' ' + str(indexRightXaxis))
            
            self.sendInstructions(motor1Speed,indexMotor1Speed, motor2Speed,indexMotor2Speed, motor3Speed,indexMotor3Speed, rightXaxis, indexRightXaxis)

    
    def sendInstructions(self, motor1Speed,indexMotor1Speed, motor2Speed,indexMotor2Speed, motor3Speed,indexMotor3Speed, rightXaxis, indexRightXaxis):
        # print('ADDRESS:' + str(self.ARDUINO_ADDRESS))
        
        with SMBusWrapper(1) as bus:
            motorSpeeds = [motor1Speed,indexMotor1Speed, motor2Speed,indexMotor2Speed, motor3Speed,indexMotor3Speed, rightXaxis, indexRightXaxis]
            bus.write_i2c_block_data(self.ARDUINO_ADDRESS, 0, motorSpeeds)

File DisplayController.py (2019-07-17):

# This is a simple class that will help us print to the screen
# It has nothing to do with the joysticks, just outputting the information.
import pygame


class DisplayController:
    def __init__(self):

        # Define some colors
        self.BLACK = (0, 0, 0)
        self.WHITE = (255, 255, 255)

        # The width and height of the display screen [width,height]
        self.screenSize = [500, 300]
        self.screen = pygame.display.set_mode(self.screenSize)
        pygame.display.set_caption("Controller Overlay")

        # Set default position of window and text line height
        self.x = 10
        self.y = 10
        self.line_height = 15

        self.reset()
        self.font = pygame.font.Font(None, 23)

        # Set window title
        pygame.display.set_caption("Controller Overlay")

    def print(self, textString):
        textBitmap = self.font.render(textString, True, self.BLACK)
        self.screen.blit(textBitmap, [self.x, self.y])
        self.y += self.line_height

    def reset(self):
        self.x = 10
        self.y = 10
        self.line_height = 15

    def indent(self):
        self.x += 10

    def unindent(self):
        self.x -= 10

    def fillScreen(self, color):
        if color == 'white':
            self.screen.fill(self.WHITE)

        elif color == 'black':
            self.screen.fill(self.BLACK)

        else:
            print('Color to fill screen not specified: exiting')
            pygame.quit()

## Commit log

2019-07-07 Class GamepadController
    Working GamepadController, added Main.py for main program flow.
2019-07-17 Added mathematics for motors, but problematic numbers
    [DisplayController.py, GamepadController.py, Main.py]
2019-07-17 Oprava matematiky v1.01
    Ze by funkcni pocitani motorku na prvni opravny pokus?
2019-07-31 I2C neodesila
2019-08-07 Funkcni komunikace s Arduinem pres I2C
2019-08-07 Pridan skript pro jednu primitivu-jizdu vpred, navrh se meni s prepoctama kol az na Arduino podle navrhu doktora
2019-08-21 Arduino commit - working bit operations - ready to run motors
2019-08-21 Pridana slozka dokumentace s aktualizovanymi poznamkami k bakalarce.
    [graf-pocet bajtu i2c na čas.xlsx, prehled_stavu_H-mustku.xlsx]
2019-11-24 Vymodelován 3D model spojovníku kol a motoru
    Také částečné úpravy dokumentace
    [Spojnik-Prechod-Kolecko-Motor.SLDPRT, Spojnik-Prechod-Kolecko-Motor.STL]
2020-03-10 Uprava kommentu konce switche Go
2020-04-21 Huge differences. Made rotation. Todo: Test scripts for response from Arduino to RPi. Shot for enable-disable pins to motors. Updated docs.
2020-04-27 All remaining Instructions made. New Test feature for response from Arduino back to RPi. Readme with manual edited. Arduino code edited with remaining instructions.
2020-04-29 Commit z Q11. Remake RPI and millis() still the same on Arduino causing not running the case of it. Text in README
2020-04-30 Made upgrades with first actual motor testings at home. Manual Arduino motor testings are working -> Rewrite in the main arduino_kod.ino file. Hope this is all and now we runnin.
2020-05-02 NTB: Some minor Arduino code updates and debugging.
2020-05-02 NTB: Last arduino changes. Made to perfection. Removed Printing for more exec. speed. Peace.
2020-05-03 NTB: Made Arduino remake into loop. Chasis is working now. Finally. Now gonna try some accelerations to dont shake.
2020-05-05 NTB: Renamed Arduino files. Deleted old one.
